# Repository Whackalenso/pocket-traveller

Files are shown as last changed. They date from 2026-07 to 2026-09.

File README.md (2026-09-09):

# Pocket Traveller

This is a Tamagotchi-inspired gadget to keep in your backpack, on your keychain, or in your pocket that encourages you to move more throughout your day.


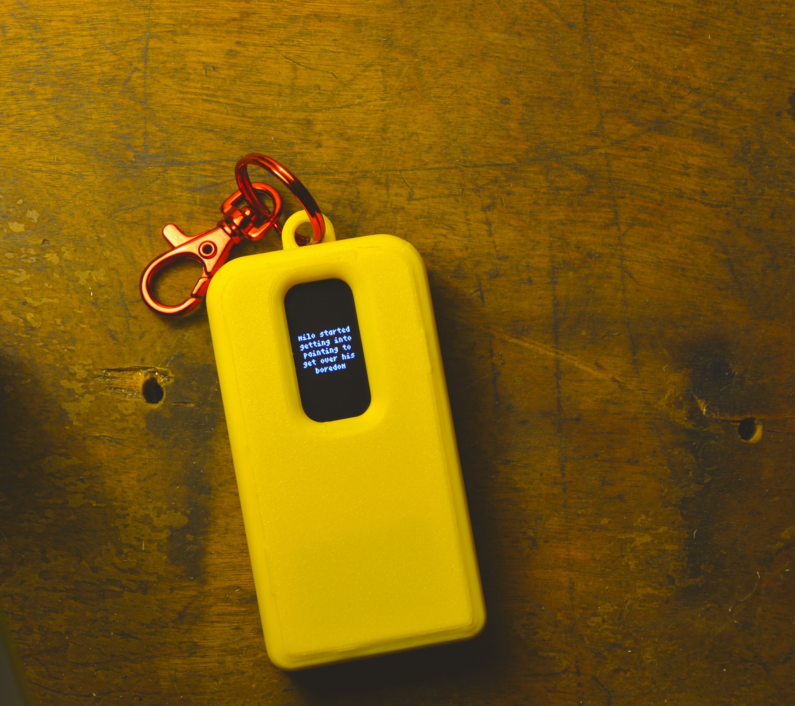
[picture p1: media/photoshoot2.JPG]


The primary feature of the device is a screen that displays an avatar named Milo. Milo will walk when you walk, rest when you're idle, and sleep during long periods of inactivity. Milo will gain **XP** the more he moves, filling up a bar at the top of the screen. When this bar fills, Milo will gain a **level**. In addition to **level**, Milo will also become a **chud**, **plebian**, or **nomad** dependent on how much he has moved in the past few days. *Skip to [Interface Design and Art](#5-interface-design-and-art) for more details*

> *The name Milo comes from the famous ancient Greek athlete, Milo of Croton. Legend has it that he would lift a newborn ox on his shoulders every day, and as the ox grew bigger, so would he. In the same way, Milo's level and state is dependent on you, as if you were the ox.*

## Hardware

* **Raspberry Pi Pico** - The brain. Reads data from the motion sensor and controls the screen.
* **SH1106** - 1.3" OLED display.
* **ADXL345** - Accelerometer. Detects instantaneous acceleration that is used to estimate longer-term motion.
* **TPU4056** - Charger module. Provides the USB-C port for charging the battery.
* **3.7v 1000mAh Lipo Battery**

All electronic components are wired together on a perfboard which is housed inside of a 3D printed case.

## Process

### 1. Breadboard Proof of Concept

#### Hardware Testing
To begin, we connected the screen and motion sensor to the Pico on a breadboard to test whether they worked properly and to figure out how to interface with them. We had some trouble finding the correct address for interfacing with our motion sensor. We got it to work eventually but ended up having to replace the sensor because it was a knockoff.

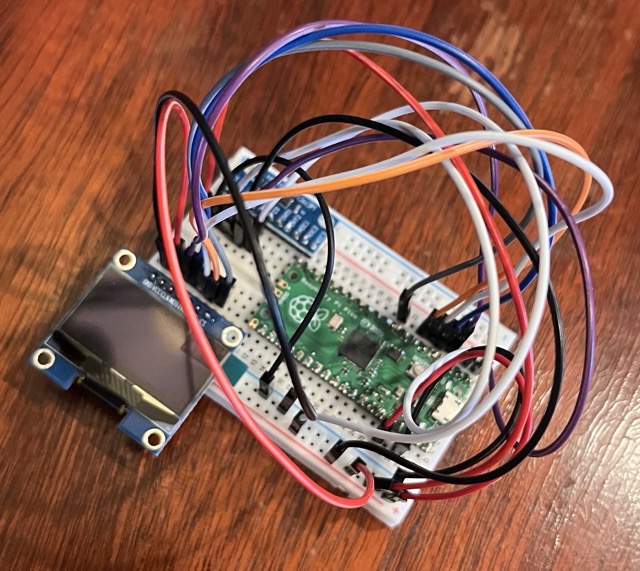
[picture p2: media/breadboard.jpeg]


#### Motion Data Classification Experiment
The next thing we needed to test is whether we could accurately classify data from the accelerometer into two states: idle and moving. This would be the core mechanism of the device, where everything else is just essentially an just interface to wrap around it. We knew this might be difficult because we chose our motion sensors to just be an accelerometer for simplicity, not an accelerometer + GPS combo. This means that the device has no reference for changes in position, only forces acted upon the device at each moment. 

After doing some research we learned that two qualities of the data can be measured in order to detect whether the user is moving: 

**Energy:** How strongly the device is moving. Measured as population variance of the magnitude of the force acted upon the sensor in a given window.<br>
**Rhythm:** How rhythmic the movements in the device are. Measured as how accurately a sequence of movements lines up with a shifted copy of itself.

The importance of this rhythm quality is that some movements may involve a lot of movement, such as shaking the device around or putting it into your backpack, however these movements shouldn't be classified as "moving". Actual "moving" scenarios, such as walking or running, will have a certain rhythm to it, as steps happen at a certain relative frequency.

Given all this, we needed to come up with thresholds for these two qualities in order to distinguish between moving and idle in a given time window. First, we made a sketch for the device that would simply display "IDLE" if the wearer is idle and "MOVING" if the wearer is moving. We played around with different values for the thresholds to see if we could create a result that seemed accurate. However, none of them seemed to work. So, abandoned trial and error and made a system to calibrate these thresholds:
1. Came up with a list of all possible movement scenarios that each give different kinds of data: sitting still, standing, fidgeting, slow walking, walking, running, and driving. Sitting still, standing, fidgeting, and driving would be classified as idle, while slow walking, walking, and running would be classified as moving. The hope/hypothesis was that there should be some value for both energy and rhythm that would separate one group from the other.
2. Created a Pico sketch for collecting energy and rhythm data
3. Recorded data for each scenario by performing the actions while holding the device
4. Created a Python script that plotted out all the data on a graph and automatically recommended thresholds for both qualities

*Recording running and driving data*

https://github.com/user-attachments/assets/422ddd09-90e0-466a-b9c1-0ad0e3300164

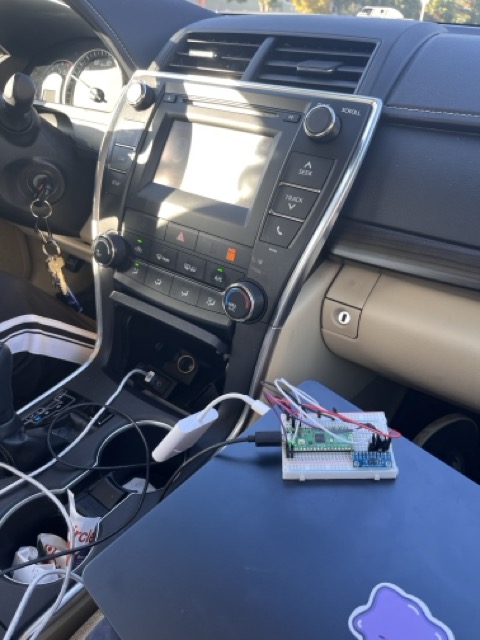
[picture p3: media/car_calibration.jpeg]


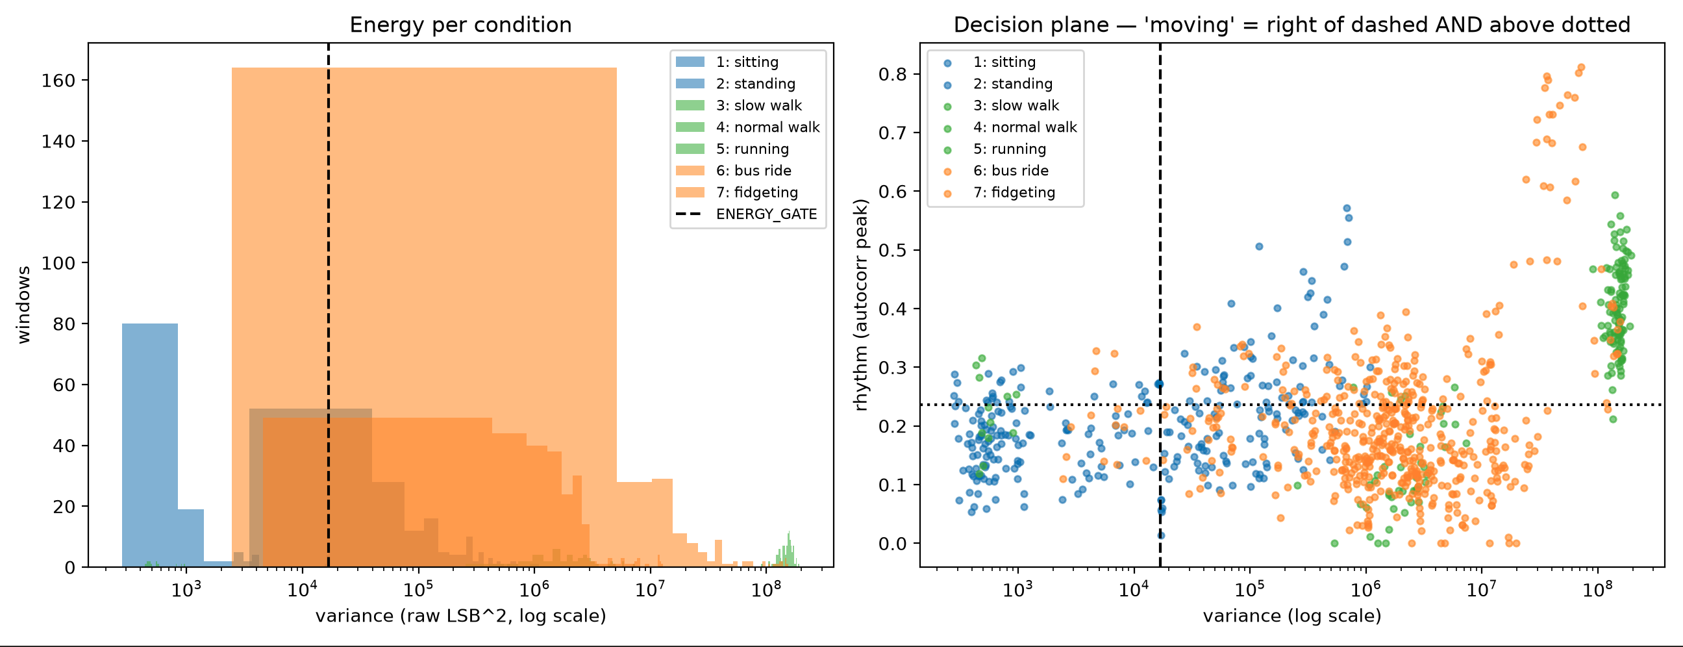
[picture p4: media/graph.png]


What we found was that the data reflected some of what we hoped: there is a clear distinction between the energy (variance) measured in "moving" states (shown in green) vs the energy measured in "idle" states. However, after looking at the graph on the right, we realized that rhythm was not necessary for distinguishing between moving and idle states, because the differences in energy alone already distinguished them. In addition, the recommended thresholds the script gave us were way off from what we observed in the graph. This didn't matter as much because we were able to look at the graph for ourselves and see where the line should be drawn, but it meant that something was off with our code and we would revisit it if needed.

We tried out our testing sketch again, but this time used 10^8 as our energy threshold and 0 for our rhythm threshold. This time, it was pretty reasonable at displaying "MOVING" when we moved with the device. However, since we weren't classifying the state with rhythm anymore, movements such as fidgeting shaking the device caused "MOVING" to be displayed as well. Our verdict was that this was good enough for now. As long as the device detects a moving state when the user is moving, it's ok that it doesn't perfectly detect and idle state. Random extra detected movement detected throughout the day will be insignificant compared to the actual long-term movement the user will actually do. The only downside is that the user may see the avatar on the screen move a little bit every now and then when they are just fidgeting with it. This will be something to revisit in the future when we have time to dive deeper into the calibration and data classification experiment.

#### Battery and Power States Proof of Concept

The next step was to test powering the device with a battery. There were a few new problems we needed to tackle:
Making sure the Pico doesn’t get damaged
Detecting that the device is being charged so that it can draw less power during this state and display a different screen
Adding a sleep state so that we can lengthen the battery life of the device without having an off button

After doing some research, we learned that routing the power from the battery through a schottkey diode was most optimal so that the charger module doesn’t get confused when detecting when the battery is full. We wired this up and the Pico didn’t blow up.

Next, we needed a way to detect whether the battery is currently being charged or not. Unfortunately, there was no dedicated pin for this on the TP4056 module. Our solution was to wire the input voltage signal– the voltage being received by the charging port– to a pin on the Pico. We had to use a voltage divider to transform this 5V signal into a 3.3V signal safe for the Pico. When this pin is read as high, we programmed the device to both draw less power (drawing power while charging the battery would confuse the charger module) and display “charging” text on the screen.

Finally, we programmed the device to go into “deep sleep” after a certain duration of inactivity. Because we chose to not have a power button on the device for simplicity, we needed a way for the device to turn off so that the battery doesn’t drain 24/7. This deep sleep state essentially powers off the Pico almost entirely. In order to wake the device up again, a special pin on the motion sensor that turns on when it detects motion can wake up the Pico even when it’s barely running.

### 3. Soldering Onto Perfboard

Now that the proof of concept was fleshed out, we could move on to soldering all the components into a more permanent and compact form that would be the innards of our final version. We began by creating a schematic in KiCad which was useful in guiding us to creating the most compact layout. Exact measurements were taken for each component to ensure our planned layout in the PCB editor was accurately spaced. This was important, especially making sure room was left for our wiring to run through the empty space in the board. Multiple wires and traces ran under components and through the back of the board, so any mistakes would be very hard to fix. Consequently, we made sure KiCad was referenced before soldering in any connections or components. Once everything was soldered in, we tested the code to make sure it ran properly. Much to our shock everything worked, so we taped down the battery to the board, trimmed the edges of the perfboard to get as compact of a design as possible and then moved on to designing the case. 

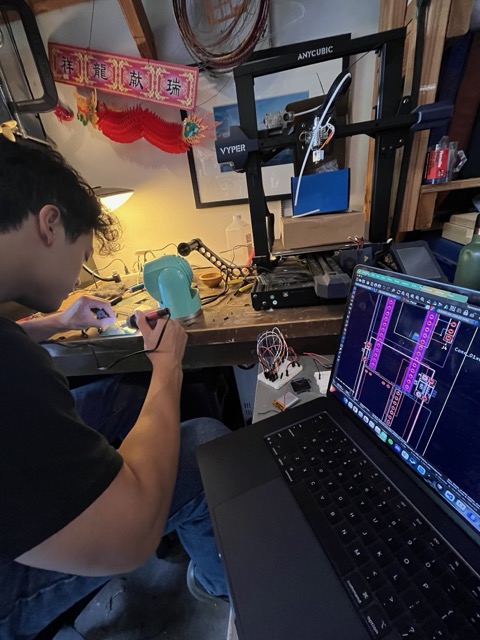
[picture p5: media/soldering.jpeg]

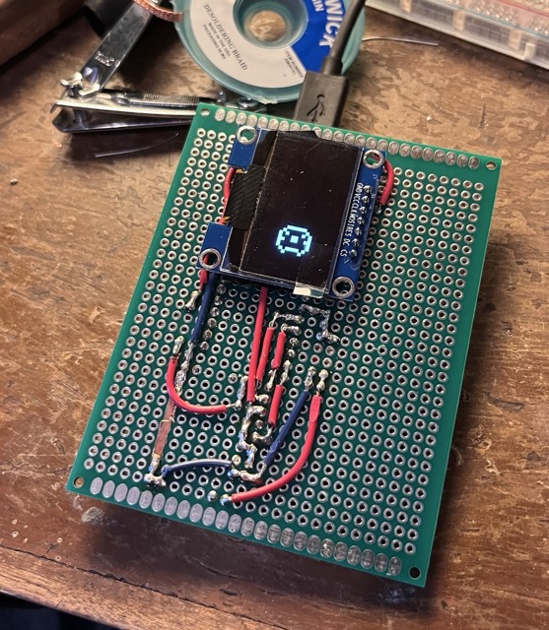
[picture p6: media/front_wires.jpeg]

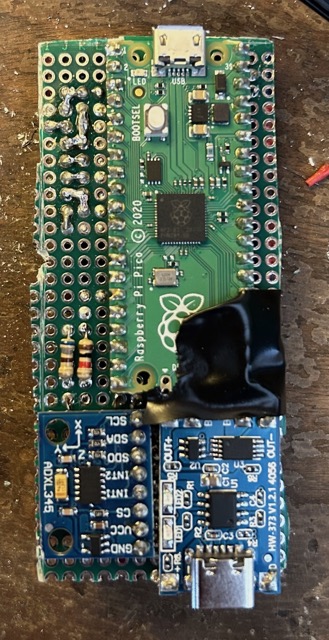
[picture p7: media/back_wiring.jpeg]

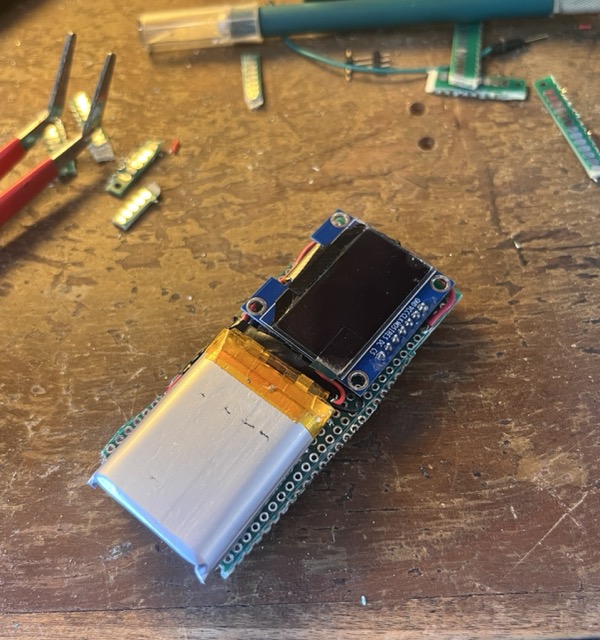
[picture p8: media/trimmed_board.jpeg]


### 4. Designing a Case

Creating a case to house our circuit board was pretty straightforward:
* Measured all the components precisely with a caliper and/or looking at datasheets.
* Modeled the dimensions of the board and electronic components in CAD
* Modeled a box in two parts, the floor and everything else, to fit around the components. This included cutouts for the screen and USB port.
* Added a standoff on both the floor and box for one screw to screw from the floor through the circuit board into the box.
* Added fillets for aesthetics.
* Added tolerances for fit.
* Added a ring at the top so that the device can be used as a keychain

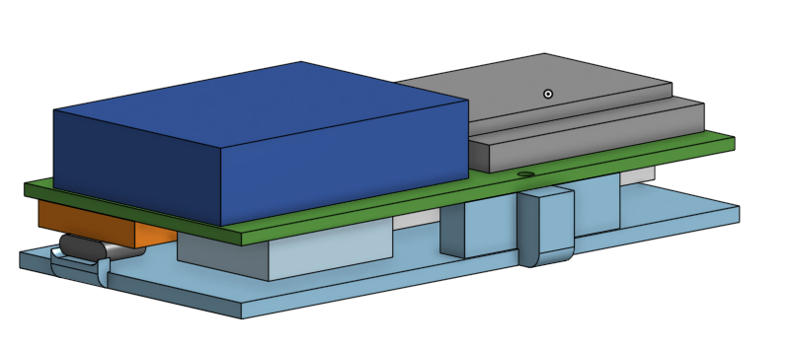
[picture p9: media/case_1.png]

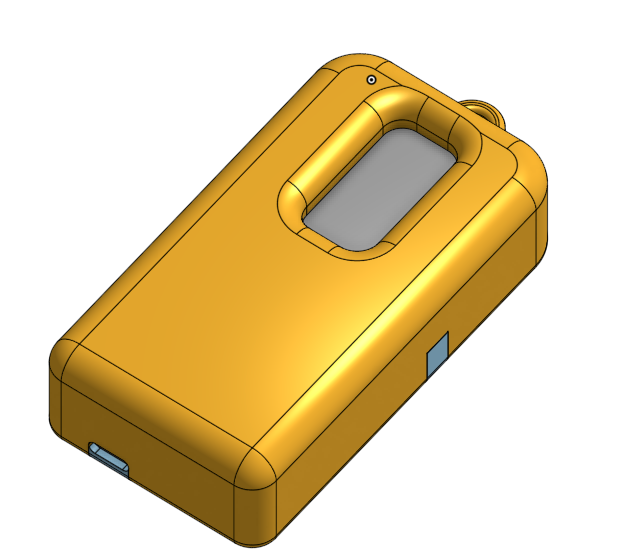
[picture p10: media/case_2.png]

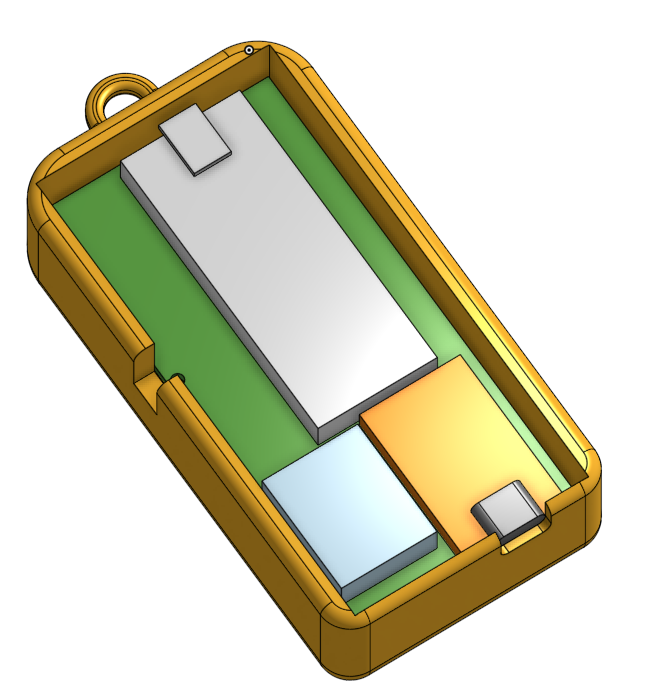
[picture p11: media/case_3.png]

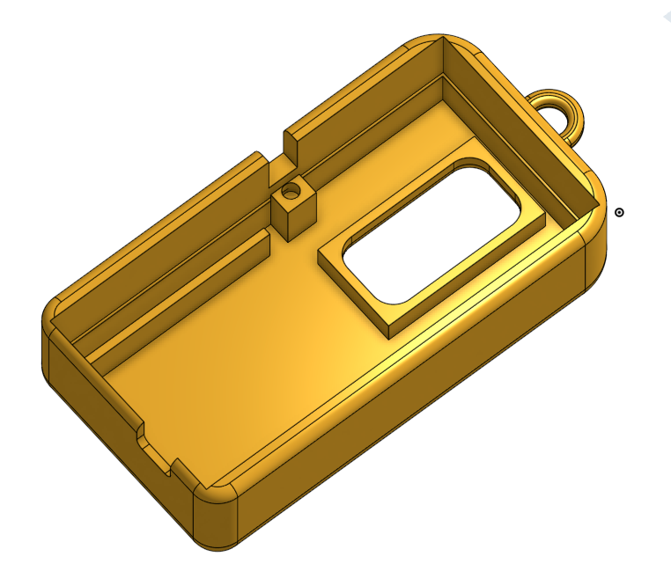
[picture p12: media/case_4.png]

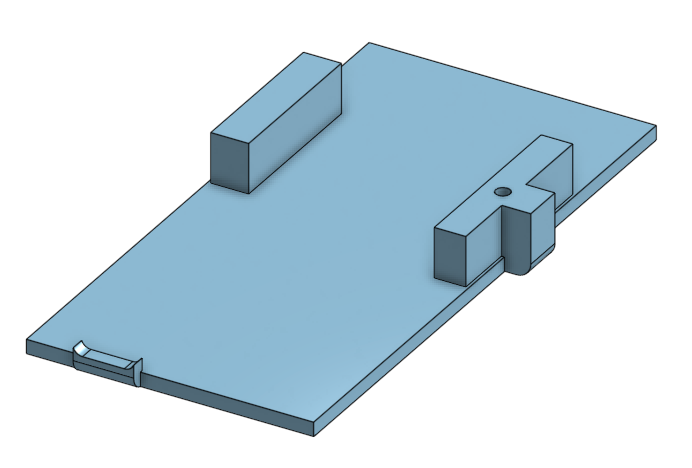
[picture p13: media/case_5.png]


### 5. Interface Design and Art

There are four main features of the user interface that make up what this device is all about: the avatar, the level, the status, and the dialogues.

#### Avatar

The avatar is the defining feature of the device. It is an animation of Milo, our made up character. The drawing style is inspired by 16x16 pixel art Tamagotchi sprites. We drew each frame ourselves using pixel art software, then used a custom Python script, gen_sprites.py, to turn each image into data readable by the Pico, stored in sprites.h. For each status, there is an animation for resting and walking.

#### Level

The level is one of the two “movement-encouraging” features. It is is reflective of your total activity in the history of owning the device: it never goes down, only up. Whenever you move, you gain XP. Once you get a certain amount of XP, you will go up one level. Your level is displayed at the top of the screen. This XP value is hidden, however, a bar below the level indicator will fill up to reflect your progress towards the next level. Each level takes more and more XP to unlock, according to a formula such that level 10 is achievable in one week and level 100 is achievable in one year.

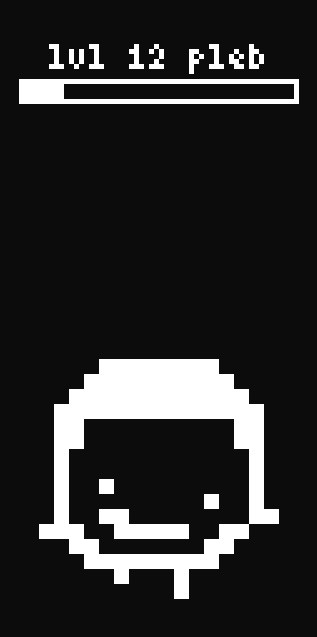
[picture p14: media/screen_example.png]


#### Status

The status is the second “movement-encouraging” feature. It is different from level in that it reflects how much you have been moving recently, as opposed to of all time. There are three statuses, “chud”, “pleb”, and “nomad”. The status indicator next to the level indicator will display one of these statuses depending on how much time in the past 72 hours you have spent moving. The current pace for each status are as follows:

Chud: <40 mins / day<br>
Pleb: ~1hr / day<br>
Nomad: >3hr / day

The threshold for promoting to a higher status is different than the threshold for demoting down to a lower rank so that sitting on the border between two statuses doesn’t cause weird issues. 

In addition to displaying your status at the top of the screen, Milo will also look different based on status:

| | Chud | Pleb | Nomad |
| :---: | :---:  | :---:  | :---: |
| **Rest** | |  |  |
| **Walk** | |  |  |

#### Dialogues

The dialogues are a feature intended to add a little more whimsy, mystery, and sometimes encouragement to the device. After a long enough period of inactivity, picking up the device will cause text to pop up on the screen saying something about what Milo is doing or thinking about. These dialogues are stored in card_lines.h. Here are some examples:

*"milo is reading feminist literature"*<br>
*"milo is workshopping his memoir"*<br>
*"milo wants to go on a hike"*<br>
*"milo is getting into lifting to get over his boredom"*

Mostly these will just be jokes, however, they are intended to also subtly hint the user towards ways they can find more fulfillment in their own life. 

---

Made with ❤️ by Nigel Weiss and Brenden Cech

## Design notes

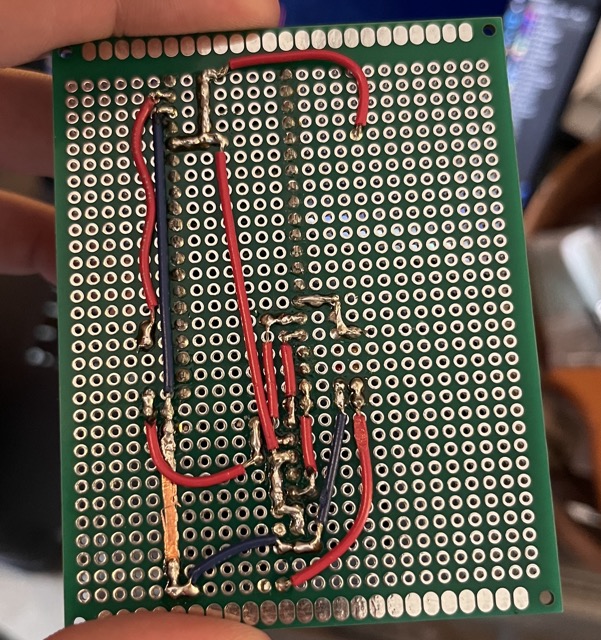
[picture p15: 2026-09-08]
media/back_wires.jpeg

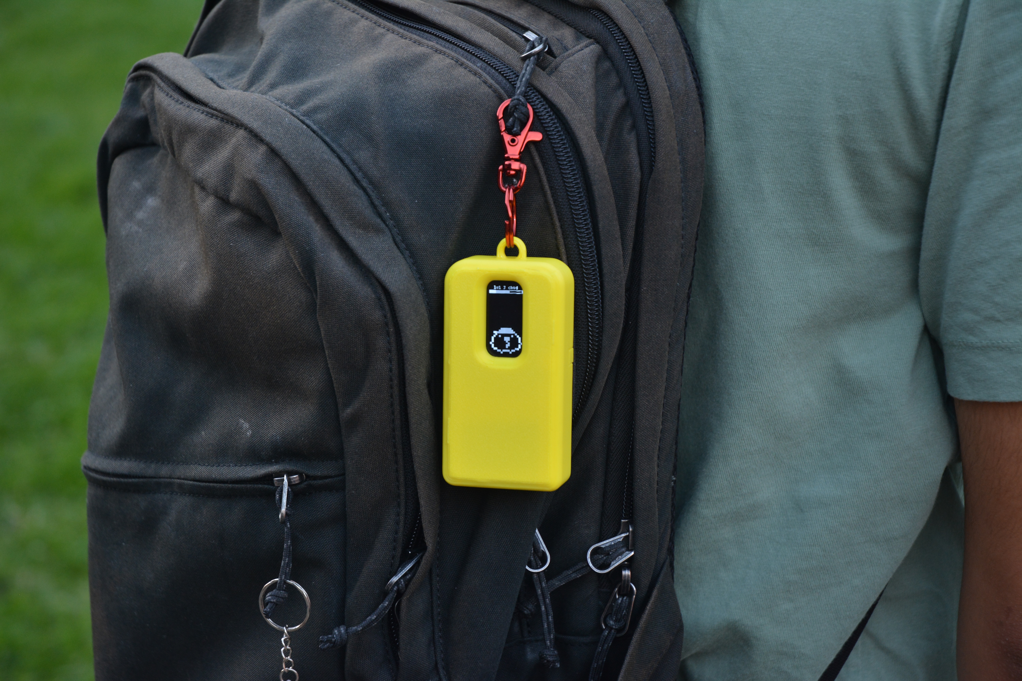
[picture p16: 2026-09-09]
media/backpack1.jpg

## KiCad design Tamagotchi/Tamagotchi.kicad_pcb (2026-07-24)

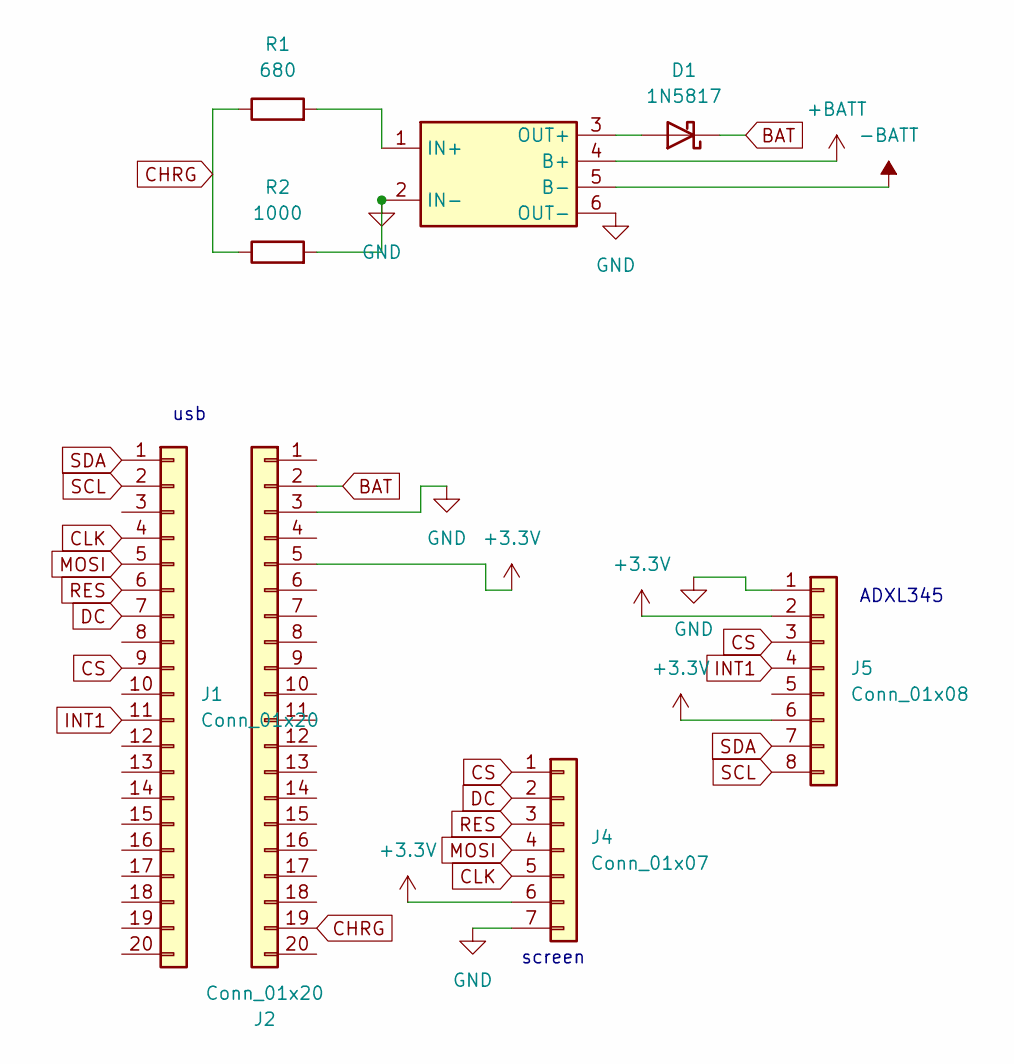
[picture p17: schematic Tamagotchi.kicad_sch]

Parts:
D1: 1N5817; D_DO-41_SOD81_P10.16mm_Horizontal
J1, J2: Conn_01x20; PinHeader_1x20_P2.54mm_Vertical
J4: Conn_01x07; Tama_Screen
J5: Conn_01x08; Tama_Sensor
R1: 680; R_0201_0603Metric
R2: 1000; R_0201_0603Metric
U1: TP4056-module; Tama_TP4056

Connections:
+3.3V: J2.5, J4.6, J5.2, J5.6
+BATT: U1.4 (B+)
-BATT: U1.5 (B-)
BAT: D1.1 (K), J2.2
CHRG: J2.19, R1.1, R2.1
CLK: J1.4, J4.5
CS: J1.9, J4.1, J5.3
DC: J1.7, J4.2
GND: J2.3, J4.7, J5.1, R2.2, U1.2 (IN-), U1.6 (OUT-)
INT1: J1.11, J5.4
MOSI: J1.5, J4.4
unnamed: D1.2 (A), U1.3 (OUT+)
unnamed: R1.2, U1.1 (IN+)
RES: J1.6, J4.3
SCL: J1.2, J5.8
SDA: J1.1, J5.7

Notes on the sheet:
screen
usb
ADXL345

Board: 2 copper layers, 8 parts (6 on the bottom side), 14 nets, no tracks yet.

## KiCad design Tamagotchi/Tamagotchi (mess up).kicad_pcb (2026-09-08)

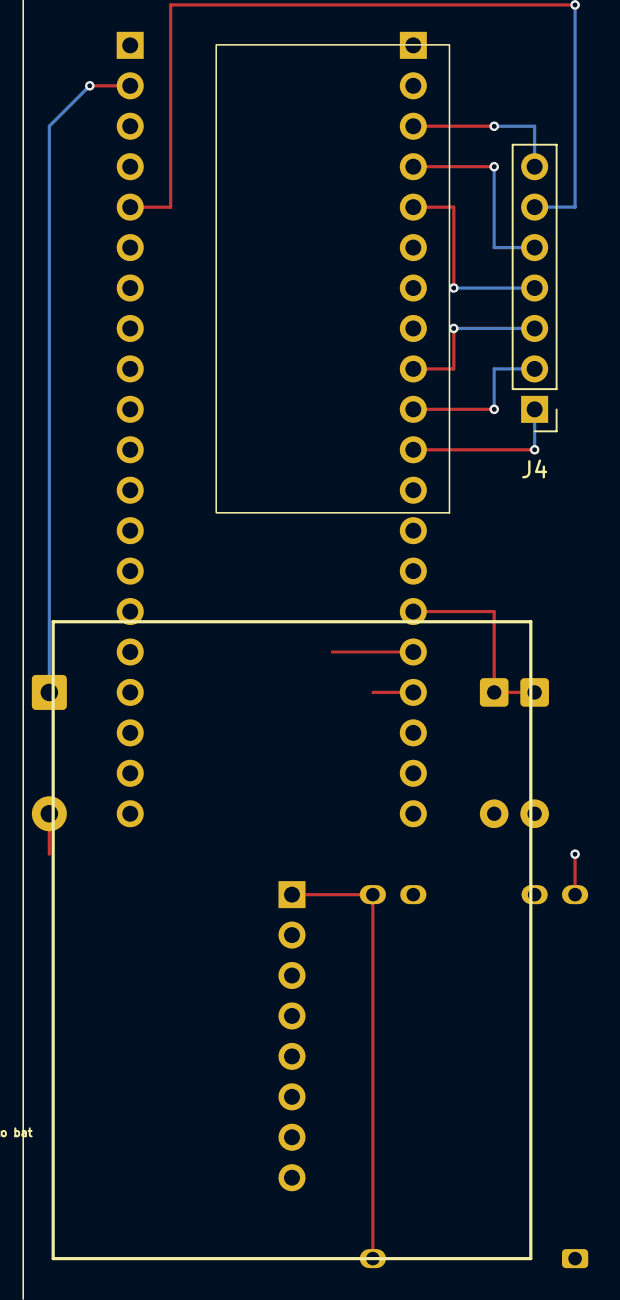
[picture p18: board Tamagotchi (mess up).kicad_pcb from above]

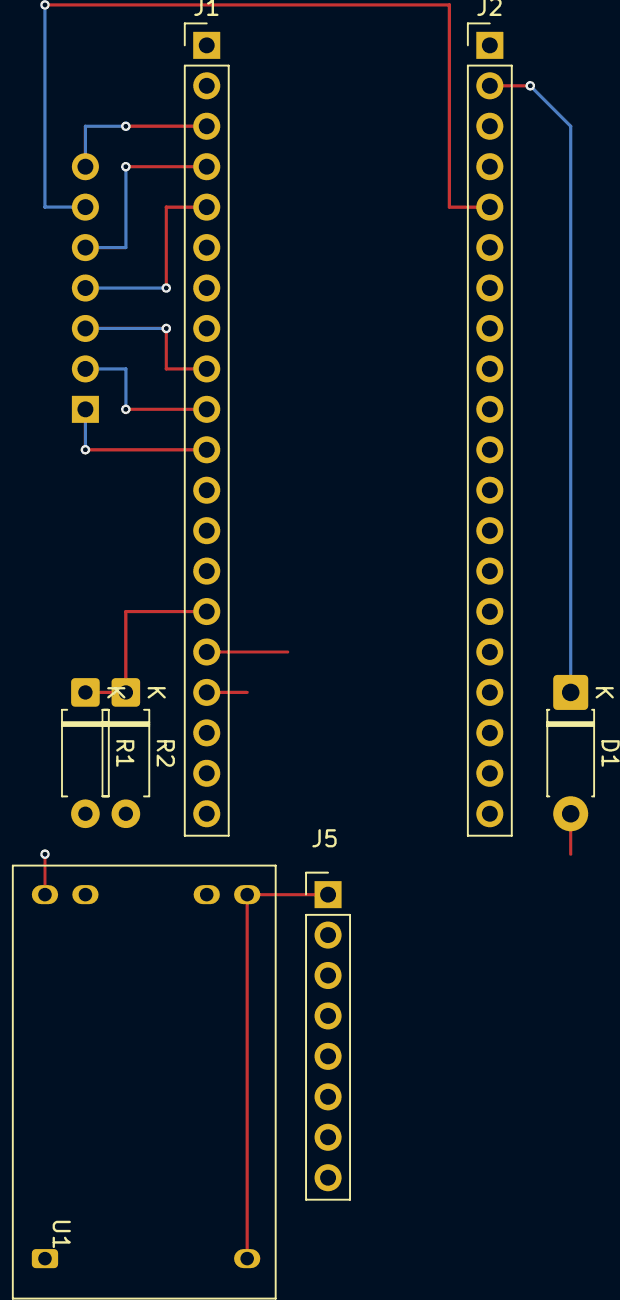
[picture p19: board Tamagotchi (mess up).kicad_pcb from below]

Board: 2 copper layers, 8 parts (7 on the bottom side), 14 nets.

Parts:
D1: 1N5817; D_DO-41_SOD81_P7.62mm_Horizontal
J1, J2: Conn_01x20; PinHeader_1x20_P2.54mm_Vertical
J4: Conn_01x07; Tama_Screen
J5: Conn_01x08; Tama_Sensor
R1: 680; D_A-405_P7.62mm_Horizontal
R2: 1000; D_A-405_P7.62mm_Horizontal
U1: TP4056-module; Tama_TP4056

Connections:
+3.3V: J2.5, J4.6, J5.2, J5.3, J5.6
BAT: D1.1 (K), J2.2
CHRG: J1.15, R1.1, R2.1
CLK: J1.4, J4.5
CS: J1.11, J4.1
DC: J1.10, J4.2
GND: J1.3, J1.8, J2.3, J4.7, J5.1, R2.2, U1.2 (IN-), U1.6 (OUT-)
INT1: J1.20, J5.4
MOSI: J1.5, J4.4
unnamed: D1.2 (A), U1.3 (OUT+)
unnamed: R1.2, U1.1 (IN+)
RES: J1.9, J4.3
SCL: J1.17, J5.8
SDA: J1.16, J5.7

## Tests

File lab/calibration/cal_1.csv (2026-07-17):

t | variance | rhythm
10.0 | 1049.3 | 0.299
10.5 | 906.4 | 0.293
11.0 | 713.7 | 0.170
11.5 | 529.7 | 0.244
12.0 | 478.9 | 0.185
12.5 | 308.7 | 0.073
13.0 | 283.1 | 0.288
13.5 | 283.3 | 0.204
14.0 | 286.8 | 0.234
14.5 | 304.5 | 0.242
15.0 | 304.8 | 0.179
15.5 | 279.3 | 0.252
16.0 | 298.2 | 0.274
16.5 | 336.7 | 0.124
17.0 | 458.2 | 0.176
17.5 | 549.3 | 0.240
18.0 | 597.6 | 0.247
18.5 | 15919.2 | 0.272
19.0 | 16562.6 | 0.272
19.5 | 16507.6 | 0.270
20.0 | 16509.5 | 0.273
20.5 | 16490.7 | 0.274
21.0 | 4171.4 | 0.152
21.5 | 607.4 | 0.251
22.0 | 584.0 | 0.179
22.5 | 575.6 | 0.151
23.0 | 533.8 | 0.194
23.5 | 535.0 | 0.059
24.0 | 432.8 | 0.128
24.5 | 552.9 | 0.174
25.0 | 652.0 | 0.240
25.5 | 697.3 | 0.275
26.0 | 712.4 | 0.223
26.5 | 718.1 | 0.184
27.0 | 1131.2 | 0.085
27.5 | 982.1 | 0.135
28.0 | 990.1 | 0.141
28.5 | 1089.7 | 0.171
29.0 | 983.2 | 0.110
29.5 | 457.2 | 0.221
30.0 | 601.7 | 0.198
30.5 | 833.2 | 0.242
31.0 | 2387.9 | 0.171
31.5 | 2926.7 | 0.109
32.0 | 3605.0 | 0.092
32.5 | 4079.3 | 0.111
33.0 | 3874.4 | 0.120
33.5 | 3286.3 | 0.084
34.0 | 1885.6 | 0.233
34.5 | 1866.7 | 0.259
35.0 | 857.0 | 0.233
35.5 | 591.5 | 0.217
36.0 | 655.3 | 0.184
36.5 | 461.8 | 0.115
37.0 | 381.5 | 0.186
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

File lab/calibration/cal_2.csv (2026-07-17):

t | variance | rhythm
10.0 | 245895.6 | 0.154
10.5 | 259322.7 | 0.144
11.0 | 286540.9 | 0.125
11.5 | 260350.5 | 0.223
12.0 | 282598.0 | 0.241
12.5 | 353994.0 | 0.316
13.0 | 418602.3 | 0.216
13.5 | 485872.9 | 0.142
14.0 | 416119.8 | 0.160
14.5 | 339558.4 | 0.240
15.0 | 229424.9 | 0.210
15.5 | 121681.1 | 0.118
16.0 | 41859.7 | 0.157
16.5 | 22027.3 | 0.131
17.0 | 23547.8 | 0.147
17.5 | 20171.4 | 0.190
18.0 | 36204.6 | 0.164
18.5 | 40362.6 | 0.293
19.0 | 49099.7 | 0.221
19.5 | 56991.7 | 0.311
20.0 | 59256.0 | 0.266
20.5 | 34926.5 | 0.136
21.0 | 14620.4 | 0.130
21.5 | 12427.0 | 0.259
22.0 | 8205.9 | 0.193
22.5 | 5489.2 | 0.113
23.0 | 5236.6 | 0.162
23.5 | 4989.0 | 0.172
24.0 | 5197.1 | 0.131
24.5 | 4884.5 | 0.115
25.0 | 3489.2 | 0.136
25.5 | 9141.5 | 0.101
26.0 | 11543.9 | 0.250
26.5 | 13214.2 | 0.192
27.0 | 37921.2 | 0.170
27.5 | 46794.9 | 0.130
28.0 | 43231.9 | 0.099
28.5 | 40764.3 | 0.120
29.0 | 54605.8 | 0.091
29.5 | 36165.7 | 0.124
30.0 | 27204.0 | 0.207
30.5 | 25201.2 | 0.212
31.0 | 25316.4 | 0.183
31.5 | 10986.2 | 0.270
32.0 | 4018.2 | 0.186
32.5 | 4529.9 | 0.250
33.0 | 6926.1 | 0.217
33.5 | 6906.1 | 0.201
34.0 | 7476.1 | 0.133
34.5 | 18208.6 | 0.153
35.0 | 22329.7 | 0.227
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

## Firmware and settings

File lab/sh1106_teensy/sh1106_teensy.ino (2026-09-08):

// sh1106_teensy.ino — SH1106 128x64 OLED bring-up on a Teensy 4.1.
//
// Run this before porting tamagotchi.ino to the Teensy. It answers, in order:
// is the panel wired and powered, is the controller variant right, is the
// 132-vs-128 column offset correct, are any rows/columns dead, and how fast
// can this board actually push a full frame.
//
// WIRING (Teensy 4.1, hardware SPI0)
//   OLED VCC -> 3.3V        (Teensy 4.x is 3.3 V only; do NOT feed it 5 V)
//   OLED GND -> GND
//   OLED CLK -> pin 13      (SCK0, fixed — also the on-board LED, see note)
//   OLED MOSI-> pin 11      (MOSI0, fixed)
//   OLED CS  -> pin 10
//   OLED DC  -> pin 9
//   OLED RES -> pin 8
//
// Only CS/DC/RES are free choices; SCK and MOSI are pinned by the SPI
// peripheral. Teensy 4.1 does offer alternates (SCK on 27, MOSI on 26) —
// uncomment the SPI.setSCK/setMOSI calls in setup() if you route them there.
//
// NOTE ON PIN 13: it drives the orange on-board LED through a buffer. That is
// harmless for SPI, but the LED will flicker with every transfer and you
// cannot use it as a status light while the display is running.
//
// HOW TO READ THE RESULTS — each screen isolates one variable.
//   1 all-on      blank or garbage -> power/wiring/CS/DC/RES, not code.
//                 black stripes    -> dead row/column driver (hardware).
//   2 checker     smeared or shifted -> wrong controller variant (see bottom).
//   3 edges       missing left/right column -> the 132-column offset is wrong;
//                 SH1106 RAM is 132 wide and the panel shows columns 2..129.
//                 Using an SSD1306 constructor on an SH1106 shifts by 2 px and
//                 drops the edge.
//   4 hline/vline dotted in one direction only -> page-addressing problem.
//                 dotted in both -> it is the glass; draw 2-px strokes.
//   5 text        confirms fonts land where you expect at this rotation.
//   6 contrast    finds the usable brightness range for battery work.
//   7 fps         full-frame refresh rate, printed to Serial.
//
// ROTATION: the tamagotchi runs U8G2_R3 (portrait). This test starts in R0 so
// a first-light failure is easy to reason about, then screen 8 repeats the
// line test under R3 to prove that code path separately.

#include <U8g2lib.h>
#include <SPI.h>

// Constructor args are (rotation, CS, DC, RESET).
U8G2_SH1106_128X64_NONAME_F_4W_HW_SPI u8g2(U8G2_R0, 10, 9, 8);

static const uint16_t DWELL_MS = 4000;

static void caption(const char* s) {
  u8g2.setFont(u8g2_font_4x6_tf);
  u8g2.drawStr(0, 6, s);
}

// 1: every pixel lit. The crudest possible check — if this is not a solid
// bright rectangle, stop and fix the hardware before reading anything else.
// Dead rows or columns show as black stripes with nothing else to hide them.
static void screenAllOn() {
  u8g2.clearBuffer();
  u8g2.drawBox(0, 0, u8g2.getDisplayWidth(), u8g2.getDisplayHeight());
  u8g2.sendBuffer();
}

// 2: 1-px checkerboard. Every pixel toggles against its neighbours, so any
// addressing or column-offset error turns this from a fine grey haze into
// visible bands or diagonal smearing.
static void screenChecker() {
  u8g2.clearBuffer();
  for (u8g2_uint_t y = 0; y < u8g2.getDisplayHeight(); y++)
    for (u8g2_uint_t x = (y & 1); x < u8g2.getDisplayWidth(); x += 2)
      u8g2.drawPixel(x, y);
  u8g2.sendBuffer();
}

// 3: outline plus corner ticks plus both diagonals. The frame must touch all
// four physical edges. A missing left or right column is the classic
// SH1106-vs-SSD1306 offset symptom; a missing top or bottom row is a page
// count or multiplex-ratio mismatch.
static void screenEdges() {
  const u8g2_uint_t w = u8g2.getDisplayWidth();
  const u8g2_uint_t h = u8g2.getDisplayHeight();
  u8g2.clearBuffer();
  u8g2.drawFrame(0, 0, w, h);
  u8g2.drawLine(0, 0, w - 1, h - 1);
  u8g2.drawLine(w - 1, 0, 0, h - 1);
  // Corner ticks: short stubs 2 px in from each corner, so you can tell a
  // clipped edge from a frame that was never drawn.
  u8g2.drawHLine(2, 2, 10);   u8g2.drawHLine(w - 12, 2, 10);
  u8g2.drawHLine(2, h - 3, 10); u8g2.drawHLine(w - 12, h - 3, 10);
  u8g2.setFont(u8g2_font_4x6_tf);
  u8g2.drawStr(w / 2 - 20, h / 2 + 3, "EDGES");
  u8g2.sendBuffer();
}

// 4: 1-px strokes in both directions on one screen. Under R0 the horizontal
// lines sit inside a single 8-row page and the vertical ones cross all eight,
// so the two halves exercise opposite paths through the controller.
static void screenLines() {
  const u8g2_uint_t w = u8g2.getDisplayWidth();
  const u8g2_uint_t h = u8g2.getDisplayHeight();
  u8g2.clearBuffer();
  caption("4 hline+vline 1px");
  for (u8g2_uint_t y = 12; y < h; y += 8) u8g2.drawHLine(0, y, w / 2 - 2);
  for (u8g2_uint_t x = w / 2 + 2; x < w; x += 8) u8g2.drawVLine(x, 10, h - 10);
  u8g2.sendBuffer();
}

// 5: a thickness ladder next to real text. If the 1-px rule looks dotted but
// the 2-px one is solid, the panel is simply losing thin strokes and the fix
// is to draw thicker, not to change constructors.
static void screenText() {
  const u8g2_uint_t w = u8g2.getDisplayWidth();
  u8g2.clearBuffer();
  u8g2.setFont(u8g2_font_4x6_tf);
  u8g2.drawStr(0, 6, "4x6 the quick brown fox");
  u8g2.setFont(u8g2_font_6x10_tf);
  u8g2.drawStr(0, 18, "6x10 Teensy 4.1");
  u8g2.setFont(u8g2_font_ncenB08_tr);
  u8g2.drawStr(0, 32, "SH1106 OK?");
  u8g2.drawHLine(0, 40, w);      // 1 px
  u8g2.drawBox(0, 46, w, 2);     // 2 px
  u8g2.drawBox(0, 54, w, 3);     // 3 px
  u8g2.sendBuffer();
}

// 6: contrast sweep against a fixed pattern. SH1106 contrast is a current
// setting, so it maps almost directly to panel power draw — worth knowing
// before this runs on a battery. Leaves contrast back at the default.
static void screenContrast() {
  static const uint8_t LEVELS[] = {0, 32, 96, 160, 255};
  for (uint8_t i = 0; i < sizeof(LEVELS); i++) {
    u8g2.setContrast(LEVELS[i]);
    u8g2.clearBuffer();
    u8g2.setFont(u8g2_font_6x10_tf);
    char buf[24];
    snprintf(buf, sizeof(buf), "contrast %u", LEVELS[i]);
    u8g2.drawStr(2, 12, buf);
    u8g2.drawBox(2, 20, 60, 20);
    for (u8g2_uint_t x = 68; x < u8g2.getDisplayWidth() - 2; x += 2)
      u8g2.drawVLine(x, 20, 20);
    u8g2.sendBuffer();
    delay(1200);
  }
  u8g2.setContrast(255);
}

// 7: full-frame throughput. Draws 60 frames of a moving box and reports the
// achieved rate. This is the number that tells you whether sprite animation
// has headroom, and it is where a too-slow bus clock shows up.
static void screenFps() {
  const u8g2_uint_t w = u8g2.getDisplayWidth();
  const u8g2_uint_t h = u8g2.getDisplayHeight();
  const uint16_t FRAMES = 60;
  uint32_t t0 = millis();
  for (uint16_t f = 0; f < FRAMES; f++) {
    u8g2.clearBuffer();
    caption("7 fps");
    u8g2_uint_t x = (uint32_t)f * (w - 16) / FRAMES;
    u8g2.drawBox(x, h / 2 - 8, 16, 16);
    u8g2.drawFrame(0, 0, w, h);
    u8g2.sendBuffer();
  }
  uint32_t dt = millis() - t0;
  float fps = dt ? (1000.0f * FRAMES / dt) : 0.0f;

  u8g2.clearBuffer();
  u8g2.setFont(u8g2_font_6x10_tf);
  char buf[24];
  snprintf(buf, sizeof(buf), "%u frames", FRAMES);
  u8g2.drawStr(2, 14, buf);
  snprintf(buf, sizeof(buf), "%lu ms", (unsigned long)dt);
  u8g2.drawStr(2, 28, buf);
  snprintf(buf, sizeof(buf), "%d.%01d fps", (int)fps, (int)(fps * 10) % 10);
  u8g2.drawStr(2, 42, buf);
  u8g2.sendBuffer();

  Serial.print("fps: ");
  Serial.print(fps);
  Serial.print("  (");
  Serial.print(dt);
  Serial.print(" ms for ");
  Serial.print(FRAMES);
  Serial.println(" full frames)");
}

// 8: the same 1-px lines under R3, the rotation the tamagotchi actually uses.
// R3 transposes the panel, so a display-space horizontal line becomes a
// controller-space vertical one crossing every page. If screen 4 was clean
// and this is dotted, the bug is in the rotated path, not the panel.
static void screenRotated() {
  u8g2.setDisplayRotation(U8G2_R3);
  const u8g2_uint_t w = u8g2.getDisplayWidth();
  const u8g2_uint_t h = u8g2.getDisplayHeight();
  u8g2.clearBuffer();
  caption("8 R3 lines");
  for (u8g2_uint_t y = 16; y < h; y += 12) u8g2.drawHLine(0, y, w);
  u8g2.drawFrame(0, 0, w, h);
  u8g2.sendBuffer();
  delay(DWELL_MS);
  u8g2.setDisplayRotation(U8G2_R0);
}

void setup() {
  // Alternate SPI0 pins on Teensy 4.1 — uncomment only if you routed them
  // there. Must be called before u8g2.begin().
  // SPI.setSCK(27);
  // SPI.setMOSI(26);

  u8g2.begin();
  u8g2.setBusClock(8000000);   // 8 MHz is safe on dupont wire; the Teensy can
                               // go far faster on a short PCB trace. If the
                               // display shows noise, lower this first.
  u8g2.setDrawColor(1);
  u8g2.setContrast(255);

  Serial.begin(115200);
  delay(2000);                 // let the host attach the port
  // deliberately no while(!Serial): must not hang when running off a battery

  Serial.println("SH1106 test — Teensy 4.1");
  Serial.print("panel ");
  Serial.print(u8g2.getDisplayWidth());
  Serial.print("x");
  Serial.println(u8g2.getDisplayHeight());
  Serial.println("1 all-on  2 checker  3 edges  4 lines  5 text  6 contrast  7 fps  8 R3");
}

void loop() {
  static const struct { const char* name; void (*draw)(); bool self_timed; } SCREENS[] = {
    {"1 all pixels on", screenAllOn,    false},
    {"2 checkerboard",  screenChecker,  false},
    {"3 edges",         screenEdges,    false},
    {"4 1px lines",     screenLines,    false},
    {"5 text ladder",   screenText,     false},
    {"6 contrast",      screenContrast, true},   // sweeps on its own clock
    {"7 fps",           screenFps,      false},
    {"8 R3 lines",      screenRotated,  true},   // manages dwell + rotation
  };
  static const uint8_t COUNT = sizeof(SCREENS) / sizeof(SCREENS[0]);
  static uint8_t i = 0;

  Serial.print("-> ");
  Serial.println(SCREENS[i].name);
  SCREENS[i].draw();
  if (!SCREENS[i].self_timed) delay(DWELL_MS);

  i = (i + 1) % COUNT;
}

// ---------------------------------------------------------------------------
// NOTHING ON SCREEN AT ALL — work down this list before touching the code:
//   * 3.3 V and GND actually reaching the module (measure at the module, not
//     at the Teensy header).
//   * RES held low permanently, or left floating on a module with no pull-up.
//   * DC and CS swapped — the two most commonly transposed wires here.
//   * A module wired for I2C. Many SH1106 boards ship jumpered for I2C and
//     need resistors moved to enable 4-wire SPI. If yours is I2C, use:
//       U8G2_SH1106_128X64_NONAME_F_HW_I2C u8g2(U8G2_R0);
//     with SDA->18, SCL->19 on the Teensy 4.1, and drop the SPI include.
//
// GARBLED OR SHIFTED IMAGE — wrong controller variant. SH1106 RAM is 132
// columns wide against a 128-column panel, and modules disagree about which
// two columns to hide and how VCOMH is set. Swap the constructor and re-run:
//
//   U8G2_SH1106_128X64_VCOMH0_F_4W_HW_SPI  u8g2(U8G2_R0, 10, 9, 8);
//   U8G2_SH1106_128X64_WINSTAR_F_4W_HW_SPI u8g2(U8G2_R0, 10, 9, 8);
//   U8G2_SSD1306_128X64_NONAME_F_4W_HW_SPI u8g2(U8G2_R0, 10, 9, 8);
//
// That last one is not a typo: modules sold as SH1106 are sometimes SSD1306.
// If the SSD1306 constructor is the one that looks right, believe it.
// ---------------------------------------------------------------------------

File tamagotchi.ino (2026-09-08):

// power_test.ino — Pico + ADXL345 (I2C 0x1D) + SH1106 SPI OLED
//
// Motion classifier + sprite playback, plus power behavior:
//   * Charging: USB 5V (TP4056 IN+) divided down and read on CHARGE_PIN.
//     Plugged in -> "charging" screen, which blanks after CHARGE_SCREEN_MS and
//     comes back on a nudge, until unplugged.
//   * Downtime: after DEEPSLEEP_AFTER_MS idle -> blank the OLED, then stop the
//     chip in RP2040 DORMANT until the ADXL345 activity interrupt wakes it.
//     (The shallower idle-sleep animation that used to precede this is
//     compiled out while there is no sleep art -- see IDLE_SLEEP_ENABLED.)
//
// WIRING
//   ADXL345:  VCC->3V3  GND->GND  SDA->GP0  SCL->GP1
//             CS ->3V3  (REQUIRED: CS low puts it in SPI mode)
//             SDO->3V3  (gives address 0x1D; SDO->GND would be 0x53)
//             INT1->GP8 (only needed if WAKE_ON_INT1 is 1)
//   OLED:     CLK->GP2  MOSI->GP3  RES->GP4  DC->GP5  CS->GP6
//   CHARGE:   TP4056 IN+ --[680R]--+--[1k]-- GND, tap junction -> GP7
//             (gives ~2.98 V at 5 V in). Shared GND with Pico REQUIRED.
//
// ADXL345 gotchas baked in below:
//   * DEVID (0x00) must read 0xE5.
//   * Boots in STANDBY; POWER_CTL (0x2D) bit 3 must be set or data is frozen.
//   * Full-res is 3.9 mg/LSB, RIGHT-justified -> no >>4 shift.
//   * Counts are scaled to milli-g so 1 g = 1000, matching old tuning.

#include <Wire.h>
#include <U8g2lib.h>
#include <SPI.h>
#include <math.h>
#include <string.h>
#include <EEPROM.h>
#include "sprites.h"

#define ADDR 0x1D

// ---- Wake source selector ---------------------------------------------------
// 1 = wake from downtime using the ADXL345 hardware activity interrupt (INT1).
// 0 = wake by polling the accelerometer in software (no INT1 wire needed).
// Start at 0 to prove the sleep flow works, then try 1 to test the interrupt.
#define WAKE_ON_INT1 1

// ---- Deep sleep selector ----------------------------------------------------
// 1 = downtime really stops the chip (RP2040 DORMANT: every clock off, wake
//     only on a GPIO level). Microamps.
// 0 = downtime spins in __wfi() waiting for the pin. Correct behavior, but the
//     core stays clocked -- milliamps. This is the fallback if dormant misbehaves
//     on real hardware; nothing else in the sketch changes.
#define TRUE_DEEP_SLEEP 1

#if TRUE_DEEP_SLEEP
#if !WAKE_ON_INT1
#error "TRUE_DEEP_SLEEP requires WAKE_ON_INT1=1: a dormant chip cannot poll the ADXL345."
#endif
#if !defined(PICO_RP2040)
#error "The dormant path is RP2040-only (xosc_dormant + clk_rtc do not exist on RP2350)."
#endif
#include "pico/runtime_init.h"          // clocks_init()
#include "hardware/clocks.h"            // clock_configure, clock_stop, set_sys_clock_khz
#include "hardware/gpio.h"              // gpio_set_dormant_irq_enabled
#include "hardware/pll.h"               // pll_deinit
#include "hardware/xosc.h"              // xosc_dormant
#include "hardware/regs/rosc.h"
#include "hardware/structs/clocks.h"
#include "hardware/structs/rosc.h"
#endif

// ---------------- power pins -------------------------------------------------
static const uint8_t CHARGE_PIN = 11;   // HIGH = USB plugged into TP4056
static const uint8_t INT1_PIN   = 15;   // ADXL345 INT1 (active HIGH on activity)

// Idle time before the Pico drops into the sleep wait.
// Set short while testing; raise for real use.
static const unsigned long DEEPSLEEP_AFTER_MS = 10UL * 60UL * 1000UL;   // 10 minutes

// How long the charging screen stays lit before it blanks. A charge is hours
// long and this panel is a mono OLED, so a permanently lit "charging" would
// eventually ghost into every frame drawn after it.
static const unsigned long CHARGE_SCREEN_MS = 10UL * 1000UL;            // 10 seconds

// ======================= TUNE THESE =========================================
float ENERGY_GATE = 1000.0f;  // variance in (milli-g)^2. 1 g = 1000 mg.
float RHYTHM_TH   = 0.2f;     // autocorr peak 0..1 in the step band.

// Short-window energy that means "a hand is on this thing right now".
// Same units as ENERGY_GATE but measured over ~200 ms instead of 2.5 s, so it
// reacts before the device reaches your face. ~4000 is ~63 mg RMS of wobble:
// well above resting sensor noise, well below a deliberate pickup.
float HANDLE_GATE = 4000.0f;

// ---- Idle sleep -------------------------------------------------------------
// Idle sleep is the shallow one: the pet dozes off with its own sprite still on
// screen after IDLE_SLEEP_MS, well before DEEPSLEEP_AFTER_MS blanks the panel
// entirely. It is off right now because no rank has sleep art -- there is
// nothing to draw. To bring it back: put sleep_0.png (and any further frames)
// in every art/<rank>/ folder, re-run
//     python gen_sprites.py art sprites.h
// and the generator flips SPRITES_HAVE_SLEEP to 1, which re-enables everything
// guarded below. Nothing else has to change.
#define IDLE_SLEEP_ENABLED SPRITES_HAVE_SLEEP

#if IDLE_SLEEP_ENABLED
// Idle time before rest -> sleep animation (must be < DEEPSLEEP_AFTER_MS).
static const unsigned long IDLE_SLEEP_MS = 30UL * 1000UL;   // 30 s
#endif

// Software motion-wake threshold, in milli-g away from 1 g rest.
static const float WAKE_MOTION_MG = 1000.0f;

// ADXL345 activity threshold, 62.5 mg/LSB. 8 -> ~500 mg. Lower = touchier.
static const uint8_t ACT_THRESH = 8;

static const uint8_t SPRITE_SCALE = 3;
// ============================================================================

// SH1106 128x64, 4-wire hardware SPI. Args: rotation, CS, DC, RESET
U8G2_SH1106_128X64_NONAME_F_4W_HW_SPI u8g2(U8G2_R3, 8, 7, 6);


// ---------------- persistent state -------------------------------------------
// XP and rank live in the last 4 KB flash sector, mirrored in RAM by the core's
// EEPROM emulation. commit() erases that whole sector, so it is called only at
// the charging / downtime transitions, never from loop().

static const uint8_t  RANK_HOURS = 72;        // rank window = 3 days

// Level curve. Reaching level L costs LEVEL_A * (L-1)^LEVEL_P seconds of
// motion. The exponent is what sets the shape: it is fixed by wanting the
// year target to be only ~52x the week target while the level number goes up
// 10x, i.e. p = ln(365/7) / ln(99/9) = 1.65. LEVEL_A then falls out of the
// week target and lands on a round 1000 s.
//
// Against a typical campus day of ~90 min of walking that gives:
//   lvl 2 = 17 min of motion     lvl 10 = 10.4 h   (1 week)
//   lvl 20 = 36 h  (3.4 weeks)   lvl 100 = 545 h   (1 year)
// Per-level cost grows from 17 min at the bottom to ~9 h at level 100.
// If real wearers move more or less than that, scale LEVEL_A and leave the
// exponent alone: it is what holds the week:year ratio, at any activity level.
static const float LEVEL_A = 1000.0f;         // seconds of motion for level 2
static const float LEVEL_P = 1.65f;
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

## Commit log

2026-07-20 new format
    [Tamagotchi.kicad_pcb, Tamagotchi.kicad_sch, cal_1.csv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]
2026-07-23 schematic updated
    [Tamagotchi.kicad_sch]
2026-09-08 tamagotchif older
    [Tamagotchi (mess up).kicad_pcb, Tamagotchi.kicad_sch]
2026-09-09 change video
    Updated the link for user attachments in the README.
